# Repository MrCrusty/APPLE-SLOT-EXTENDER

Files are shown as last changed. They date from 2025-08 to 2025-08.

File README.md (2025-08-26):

# Apple 2 & 2e slot extender
# I will start off by saying that this is my first time posting a GitHub project and also the first time I have had a PCB fabricated commercially.
## Why do I want an Apple 2 or 2e slot extender?
### Its very tight and dark to probe a card inside the case of a Vintage Apple 2e computer, especially as there are a lot of bare live parts that can be contacted or shorted inside the case and on the Apple mother board.
Thus getting the card under test outside the case is a must for keeping my Apple well and running into the next decade.
Apple Card extenders are hard to source at the moment in the year 2025, so I decided to have a go at making my own.

I have used Kicad 9 to design the passive circuit and produce the PCB.

Not all of the design is my work as I asked contributor markdev if I could use one of his card edge footprints. And you can see his very kind reply agreeing to my use of his hard work.

*Hey there, yes that would be OK. The footprint is in this file https://github.com/markadev/AppleII-VGA/blob/main/AppleVGA/AppleVGA.pretty/AppleIIBus_Edge.kicad_mod which you can copy into your own project.
I also have another footprint in this library: https://github.com/markadev/KiCad-AppleII HOWEVER it contains some small size adjustments from the one used in this project and I never got around to creating a board to test it. So it's a bit more of a risk to use.*
 
My first PCB has worked but it seems that I have used the footprint that required some adjustment. 

### It’ s pictured below and was fabricated by PCBWAY directly from the Kicad project.
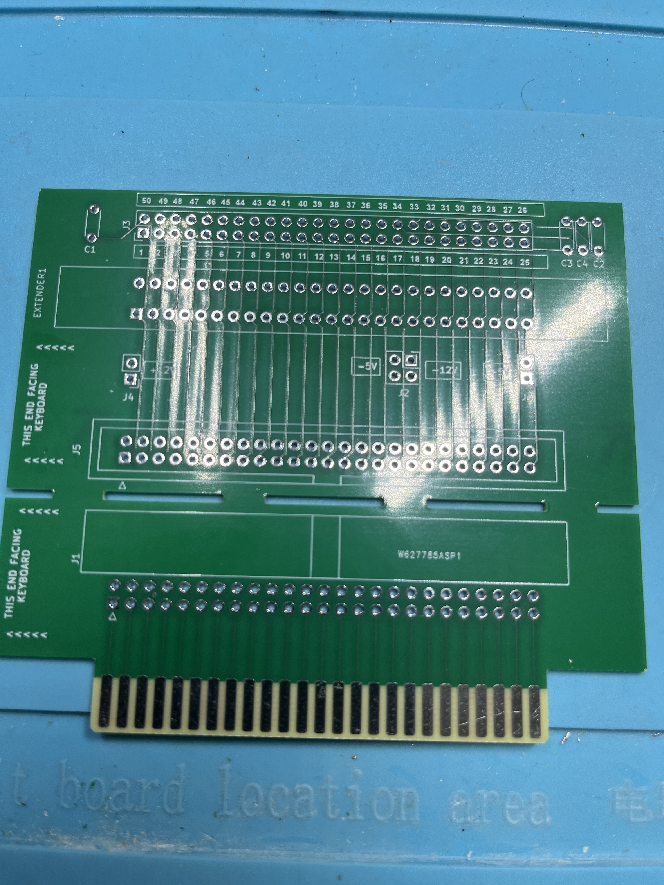
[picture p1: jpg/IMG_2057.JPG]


The center slots are to allow simple seperation with a hacksaw so that the two halves can then be joined with a 50 way ribbon cable.
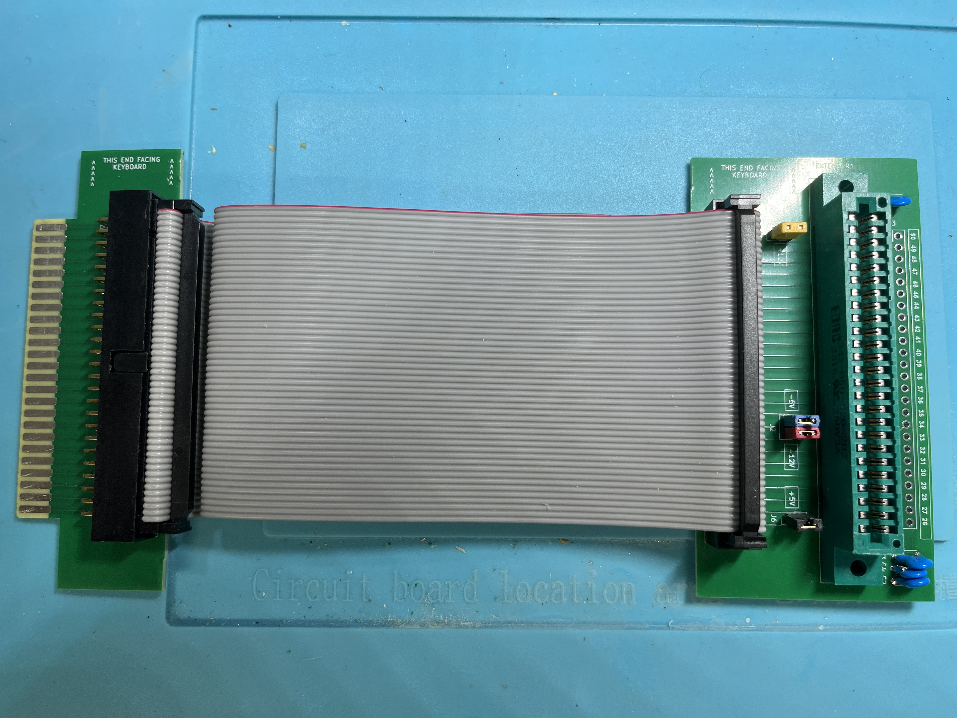
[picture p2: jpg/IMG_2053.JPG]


As stated the card edge is not quite as snug in the Apple slot as it should be so a Version 2 was designed with the card edge suitably adjusted to fit the Apple slot size snugly.
I had during the above production of Version 1 shown the 3D design to the subscribers at APPLEFRITTER.com and asked for any improvements that might be made to Version 1. I had two answers 

The first was to suggest the use of Electroless Nickel Immersion Gold (ENIG) instead of tin.

## Version 2 nearly stalled at this point as it would seem that I must have had a first time deal from PCBWAY. The cost of the PCB had increased three times over Version 1 and the postage had jumped to the highest rate with no other options, if I was to request ENIG my wife would have have had me on bread and water for a month.

I decided to have a trawl on the web and see if other companies offered better deals 
## AISLER has come to my rescue offering a resonable PCB production cost downloaded direct from my Kicad project with resonable postage rates from Germany to the UK. ENIG was 3 Euro more than tin. Version 2 arrived exactly on the day that they advised and emails during the production run kept me informed of progress. 
## Version 2 meets the card edge requirements I expected and is nice and snug fit in the card socket.

## I said there was a second suggestion which was to have a silkscreen with names of the contacts related to the extension slot, this request arrived just after Version 2 had been sent for production. 
## A Version 3 has been designed with the new silk screen and components adjusted to allow the the extended size of the silk screen, its not been sent for production but uses exactly the same edge connector as Version 2.
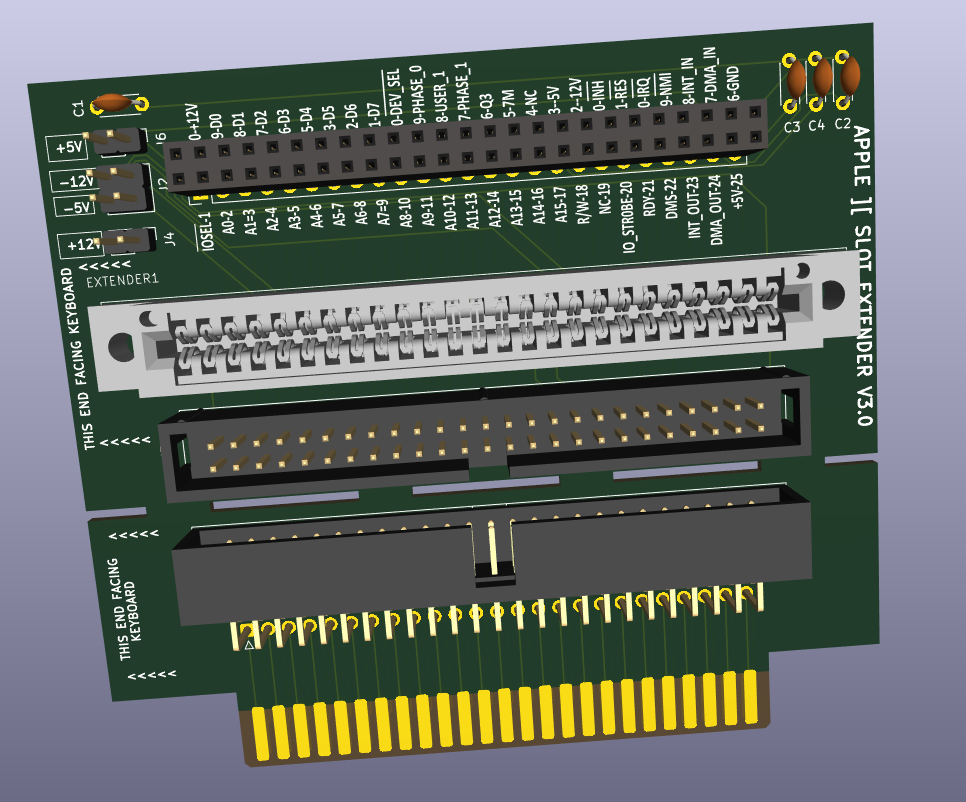
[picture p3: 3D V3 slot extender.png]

# On the subject of downloading the Kicad 9 project files.
## If you just want to have a copy of the project files CLICK ON THE GREEN BUTTON and select "download zip" option this will give you all the files and pictures in this repository, pictures are large in bytes, so I tend to delete when I have the unzipped file on my local machine. 
### If you want to Fork this project be my guest. 
### I do not intend to sell these cards myself but if you want to manufacture for sale please make sure you donate to Kicad.

# Please be aware you can plug a card in back to front with terrible results to the card and the Apple computer so do take care when using the extender. 
# LIKE ALL MY PROJECTS ITS FREE TO USE AND ABUSE, BUT I DO NOT TAKE RESPONSIBILITY THAT YOU APPLE COMPUTER WILL LIKE OR BE ABLE TO USE THIS EXTENDER. MINE IS HAPPY WITH IT YOURS MAY NOT BE> 
Some previous web discussion with regard to cable extenders suggest they cause timing problems. 
At the bus speed of the Apple if you get this problem then you probably have a design problem on the card anyway, how ever the ribbon cable may generate crosstalk as each active ribbon cable is not seperated by a ground line.

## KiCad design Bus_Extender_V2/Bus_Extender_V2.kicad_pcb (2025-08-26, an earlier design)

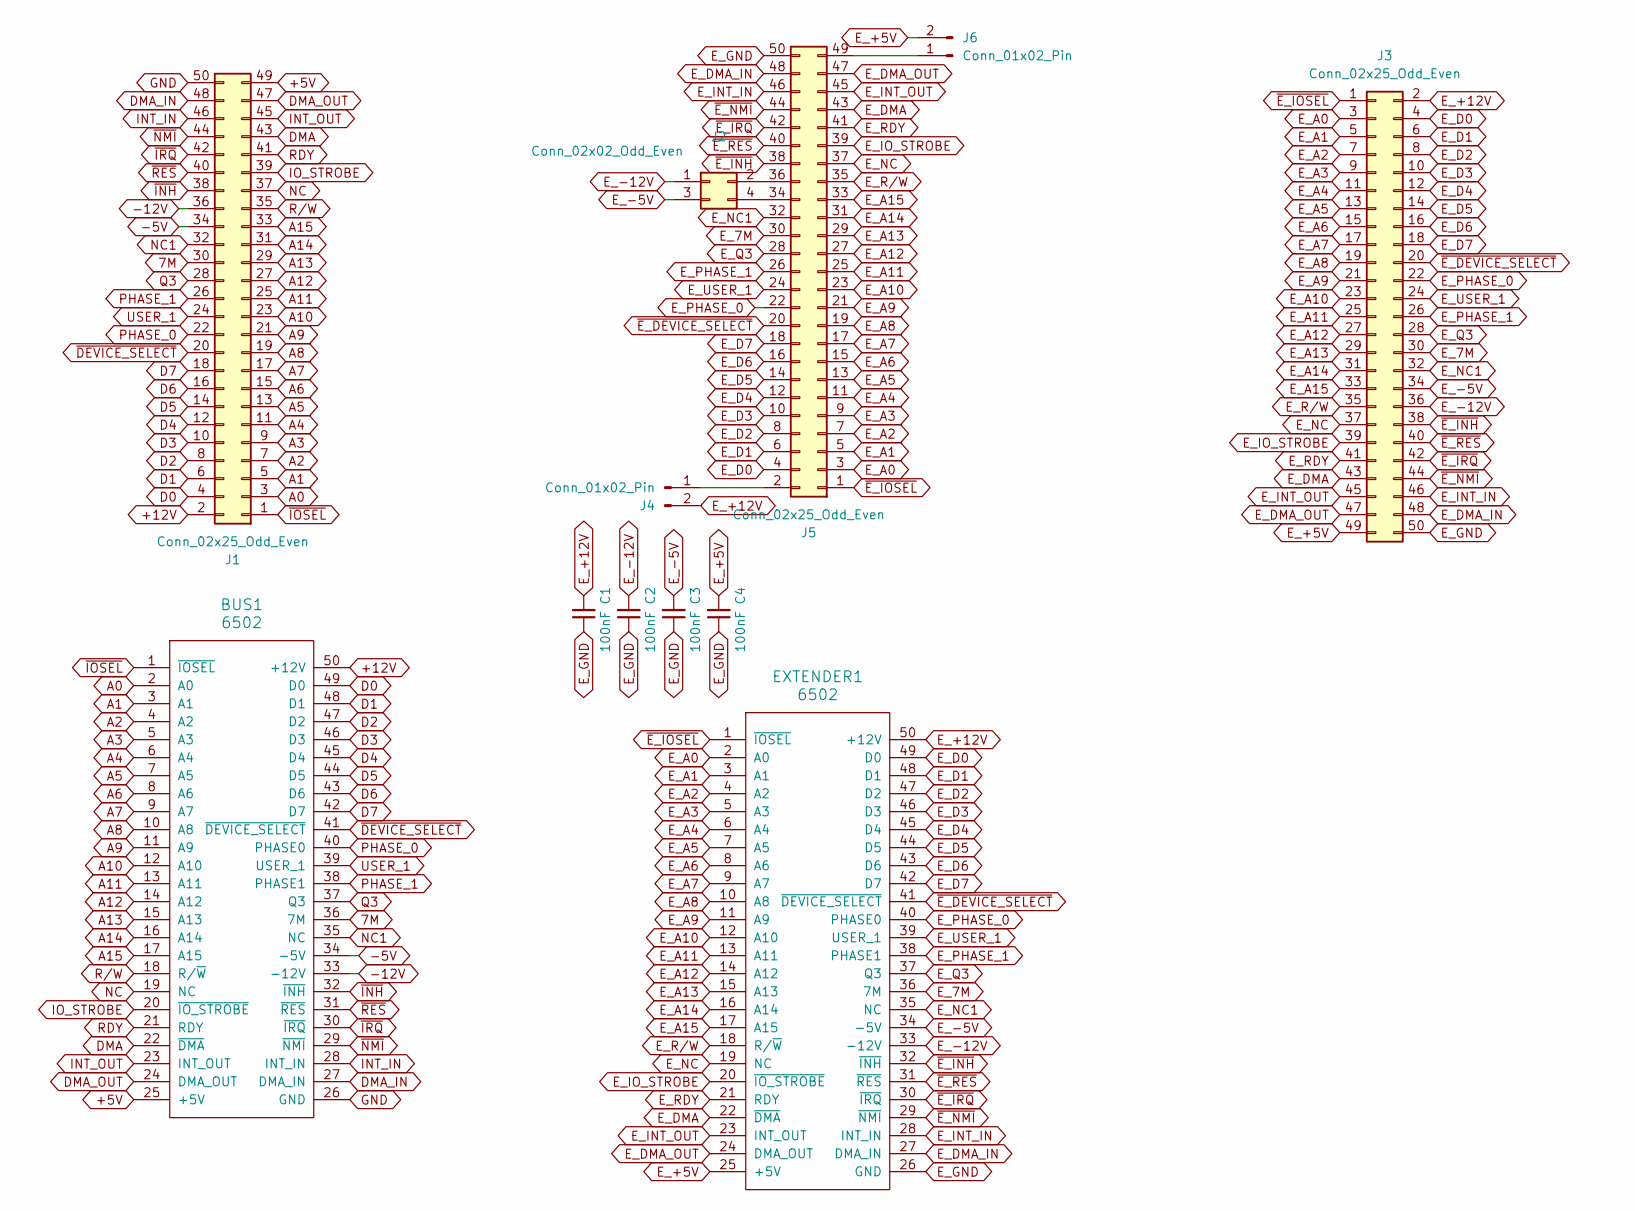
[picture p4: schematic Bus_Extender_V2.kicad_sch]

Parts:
BUS1: 6502; AppleIIBus_Edge_65.70
C1, C2, C3, C4: 100nF; C_Disc_D4.3mm_W1.9mm_P5.00mm
EXTENDER1: 6502; BUS_6502_v1
J1: Conn_02x25_Odd_Even; IDC-Header_2x25_P2.54mm_Horizontal
J2: Conn_02x02_Odd_Even; PinHeader_2x02_P2.54mm_Vertical
J3: Conn_02x25_Odd_Even; PinSocket_2x25_P2.54mm_Vertical
J4, J6: Conn_01x02_Pin; PinHeader_1x02_P2.54mm_Vertical
J5: Conn_02x25_Odd_Even; IDC-Header_2x25_P2.54mm_Vertical

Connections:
7M: BUS1.36 (7M), J1.30
+5V: BUS1.25 (+5V), J1.49
+12V: BUS1.50 (+12V), J1.2
-5V: BUS1.34 (-5V), J1.34
-12V: BUS1.33 (-12V), J1.36
A0: BUS1.2 (A0), J1.3
A1: BUS1.3 (A1), J1.5
A2: BUS1.4 (A2), J1.7
A3: BUS1.5 (A3), J1.9
A4: BUS1.6 (A4), J1.11
A5: BUS1.7 (A5), J1.13
A6: BUS1.8 (A6), J1.15
A7: BUS1.9 (A7), J1.17
A8: BUS1.10 (A8), J1.19
A9: BUS1.11 (A9), J1.21
A10: BUS1.12 (A10), J1.23
A11: BUS1.13 (A11), J1.25
A12: BUS1.14 (A12), J1.27
A13: BUS1.15 (A13), J1.29
A14: BUS1.16 (A14), J1.31
A15: BUS1.17 (A15), J1.33
D0: BUS1.49 (D0), J1.4
D1: BUS1.48 (D1), J1.6
D2: BUS1.47 (D2), J1.8
D3: BUS1.46 (D3), J1.10
D4: BUS1.45 (D4), J1.12
D5: BUS1.44 (D5), J1.14
D6: BUS1.43 (D6), J1.16
D7: BUS1.42 (D7), J1.18
DMA: BUS1.22 (~DMA), J1.43
DMA_IN: BUS1.27 (DMA_IN), J1.48
DMA_OUT: BUS1.24 (DMA_OUT), J1.47
E_7M: EXTENDER1.36 (7M), J3.30, J5.30
E_+5V: C4.2, EXTENDER1.25 (+5V), J3.49, J6.2
E_+12V: C1.2, EXTENDER1.50 (+12V), J3.2, J4.2
E_-5V: C3.2, EXTENDER1.34 (-5V), J2.3, J3.34
E_-12V: C2.2, EXTENDER1.33 (-12V), J2.1, J3.36
E_A0: EXTENDER1.2 (A0), J3.3, J5.3
E_A1: EXTENDER1.3 (A1), J3.5, J5.5
E_A2: EXTENDER1.4 (A2), J3.7, J5.7
E_A3: EXTENDER1.5 (A3), J3.9, J5.9
E_A4: EXTENDER1.6 (A4), J3.11, J5.11
E_A5: EXTENDER1.7 (A5), J3.13, J5.13
E_A6: EXTENDER1.8 (A6), J3.15, J5.15
E_A7: EXTENDER1.9 (A7), J3.17, J5.17
E_A8: EXTENDER1.10 (A8), J3.19, J5.19
E_A9: EXTENDER1.11 (A9), J3.21, J5.21
E_A10: EXTENDER1.12 (A10), J3.23, J5.23
E_A11: EXTENDER1.13 (A11), J3.25, J5.25
E_A12: EXTENDER1.14 (A12), J3.27, J5.27
E_A13: EXTENDER1.15 (A13), J3.29, J5.29
E_A14: EXTENDER1.16 (A14), J3.31, J5.31
E_A15: EXTENDER1.17 (A15), J3.33, J5.33
E_D0: EXTENDER1.49 (D0), J3.4, J5.4
E_D1: EXTENDER1.48 (D1), J3.6, J5.6
E_D2: EXTENDER1.47 (D2), J3.8, J5.8
E_D3: EXTENDER1.46 (D3), J3.10, J5.10
E_D4: EXTENDER1.45 (D4), J3.12, J5.12
E_D5: EXTENDER1.44 (D5), J3.14, J5.14
E_D6: EXTENDER1.43 (D6), J3.16, J5.16
E_D7: EXTENDER1.42 (D7), J3.18, J5.18
E_DMA: EXTENDER1.22 (~DMA), J3.43, J5.43
E_DMA_IN: EXTENDER1.27 (DMA_IN), J3.48, J5.48
E_DMA_OUT: EXTENDER1.24 (DMA_OUT), J3.47, J5.47
E_GND: C1.1, C2.1, C3.1, C4.1, EXTENDER1.26 (GND), J3.50, J5.50
E_INT_IN: EXTENDER1.28 (INT_IN), J3.46, J5.46
E_INT_OUT: EXTENDER1.23 (INT_OUT), J3.45, J5.45
E_IO_STROBE: EXTENDER1.20 (~IO_STROBE), J3.39, J5.39
E_NC: EXTENDER1.19 (NC), J3.37, J5.37
E_NC1: EXTENDER1.35 (NC), J3.32, J5.32
E_PHASE_0: EXTENDER1.40 (PHASE0), J3.22, J5.22
E_PHASE_1: EXTENDER1.38 (PHASE1), J3.26, J5.26
E_Q3: EXTENDER1.37 (Q3), J3.28, J5.28
E_RDY: EXTENDER1.21 (RDY), J3.41, J5.41
E_R/W: EXTENDER1.18 (R/~W), J3.35, J5.35
E_USER_1: EXTENDER1.39 (USER_1), J3.24, J5.24
GND: BUS1.26 (GND), J1.50
INT_IN: BUS1.28 (INT_IN), J1.46
INT_OUT: BUS1.23 (INT_OUT), J1.45
IO_STROBE: BUS1.20 (~IO_STROBE), J1.39
NC: BUS1.19 (NC), J1.37
NC1: BUS1.35 (NC), J1.32
unnamed: J2.2, J5.36
unnamed: J2.4, J5.34
unnamed: J4.1, J5.2
unnamed: J5.49, J6.1
PHASE_0: BUS1.40 (PHASE0), J1.22
PHASE_1: BUS1.38 (PHASE1), J1.26
Q3: BUS1.37 (Q3), J1.28
RDY: BUS1.21 (RDY), J1.41
R/W: BUS1.18 (R/~W), J1.35
USER_1: BUS1.39 (USER_1), J1.24
~DEVICE_SELECT: BUS1.41 (~DEVICE_SELECT), J1.20
~E_DEVICE_SELECT: EXTENDER1.41 (~DEVICE_SELECT), J3.20, J5.20
~E_INH: EXTENDER1.32 (~INH), J3.38, J5.38
~E_IOSEL: EXTENDER1.1 (~IOSEL), J3.1, J5.1
~E_IRQ: EXTENDER1.30 (~IRQ), J3.42, J5.42
~E_NMI: EXTENDER1.29 (~NMI), J3.44, J5.44
~E_RES: EXTENDER1.31 (~RES), J3.40, J5.40
~INH: BUS1.32 (~INH), J1.38
~IOSEL: BUS1.1 (~IOSEL), J1.1
~IRQ: BUS1.30 (~IRQ), J1.42
~NMI: BUS1.29 (~NMI), J1.44
~RES: BUS1.31 (~RES), J1.40

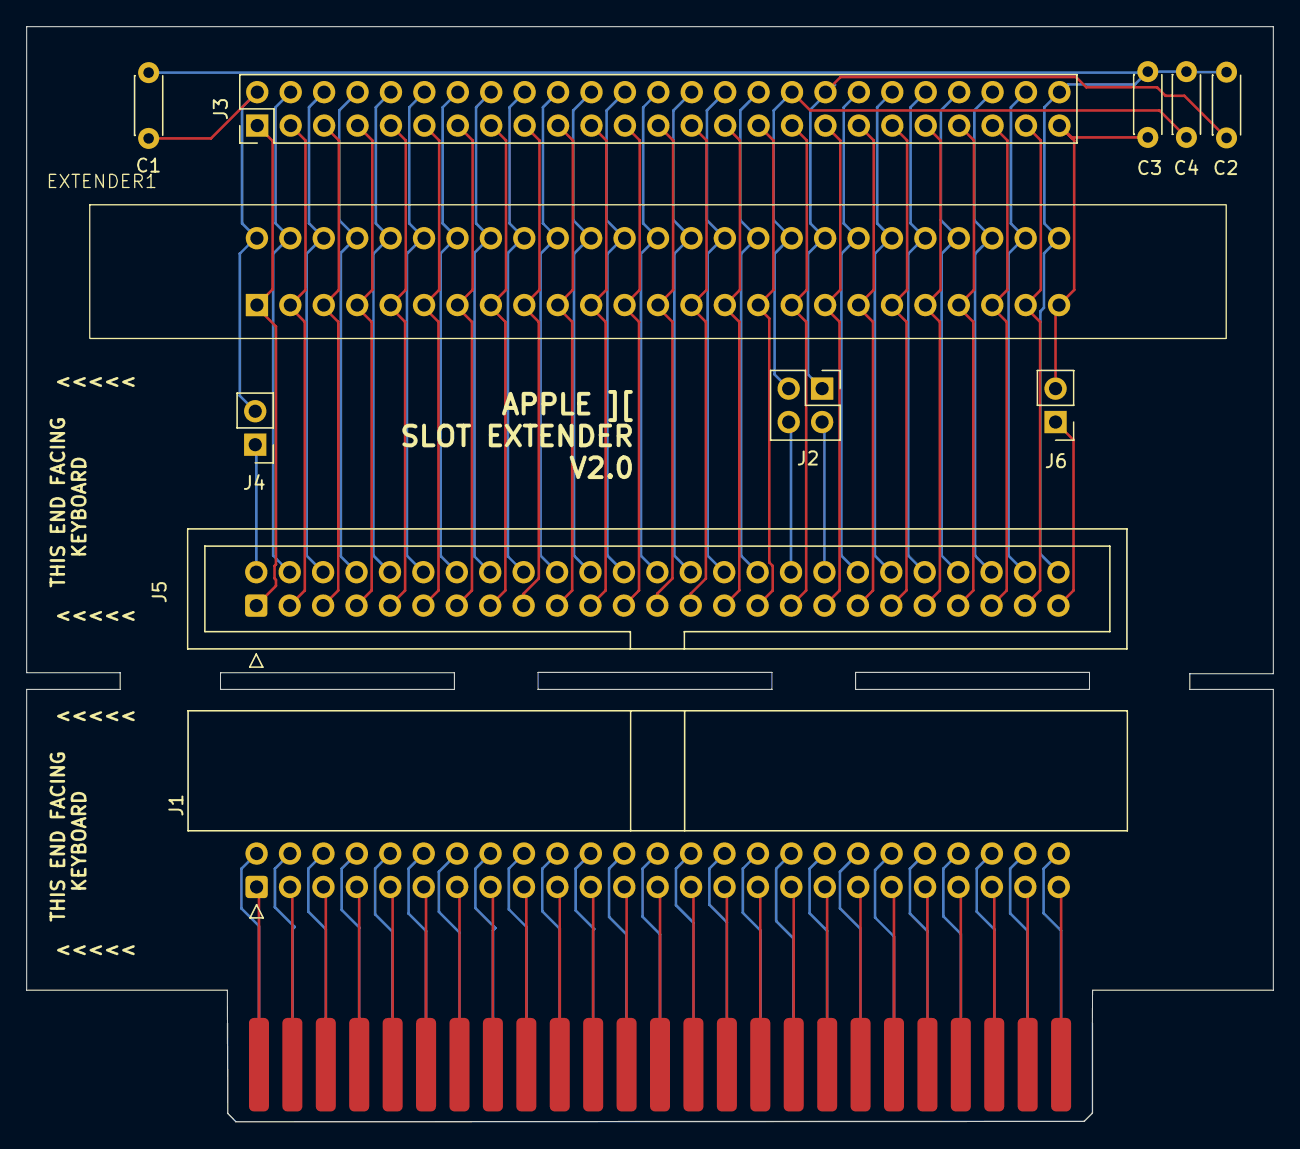
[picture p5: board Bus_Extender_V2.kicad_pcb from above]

Board: 2 copper layers, 94.7 x 83.2 mm, 12 parts (0 on the bottom side), 104 nets.
